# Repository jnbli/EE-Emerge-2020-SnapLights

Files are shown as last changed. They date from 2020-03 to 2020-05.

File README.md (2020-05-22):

# SnapLights

Snaplights is project that uses face recognition and clap detection to play the game of tic-tac-toe. It is a two-player game. In this project, 9 [Adafruit Neopixel LEDs](https://www.adafruit.com/product/1487) are arranged in 3-by-3 patterns in a wooden frame with a camera and a microphone attached to the frame. The [Open MV H7](https://openmv.io/products/openmv-cam-h7) camera is used for the face recognition, [KY-037 Microphone sensor](http://sensorkit.en.joy-it.net/index.php?title=KY-037_Microphone_sensor_module_(high_sensitivity)) for the clap detection, and the neopixels to display the output. Players choose their spot with their face and double clap to confirm. The first to claim three spots in a row wins!

# Getting Started

The early idea was to have a finger snap turn on a set of lights, by Jonathan. In discussions, Aldric convinced the team to pivot the project to be an interactive game. 

# How does Snaplights work? 
The control system of Snaplights, the MSP430G2553 is programmed using the Texas Instruments Code Composer. The code creats a UART connection between the camera and the microntroller. It also process the signal received from the microphone. The OpenMV H7 camera is programmed using OpenMV IDE, the code splits the camera lens screen into 3x3 matrices coordinates. If the face is detected in any of the sections, the corresponding neopixel will turn on to be X for the first player and at the same time if the microphone senses a clap then the displayed X will be locked in the neopixel. If a clap is not sensed then as the person moves their face onto a different section, the corresponding neopixel will turn on, turning off the previous neopixel. After locking the first input, the next player will start playing with O and follow the same process as X. 

# Assembly
This is the general assembly of the mechanical components of our project. It consists of a wooden frame, another foamboard frame to be placed within the larger frame, nine 3D printed grid assemblies to dissipate light to a greater area, and nine neopixels. 
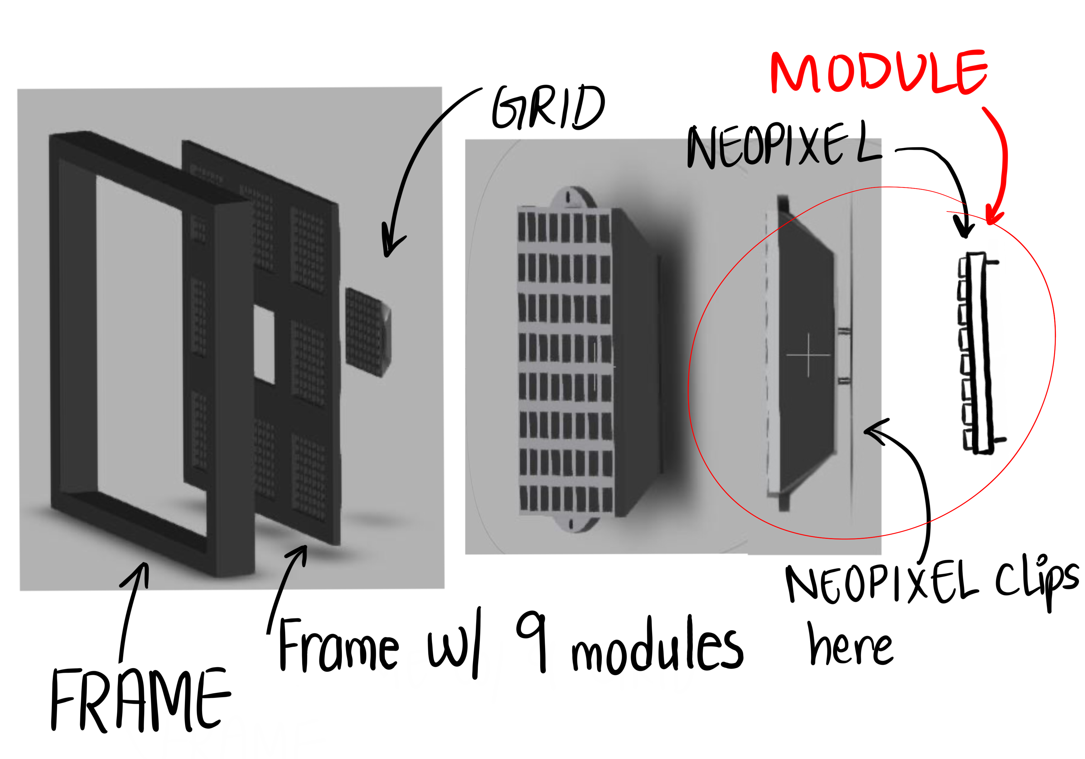
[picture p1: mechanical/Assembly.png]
Assembly


# Wiring Diagram
This is the wiring configuration of Snaplights. The diagram presents how the wires connects all the part together. DaisyChain is the type of wiring scheme used for the neopixels. 
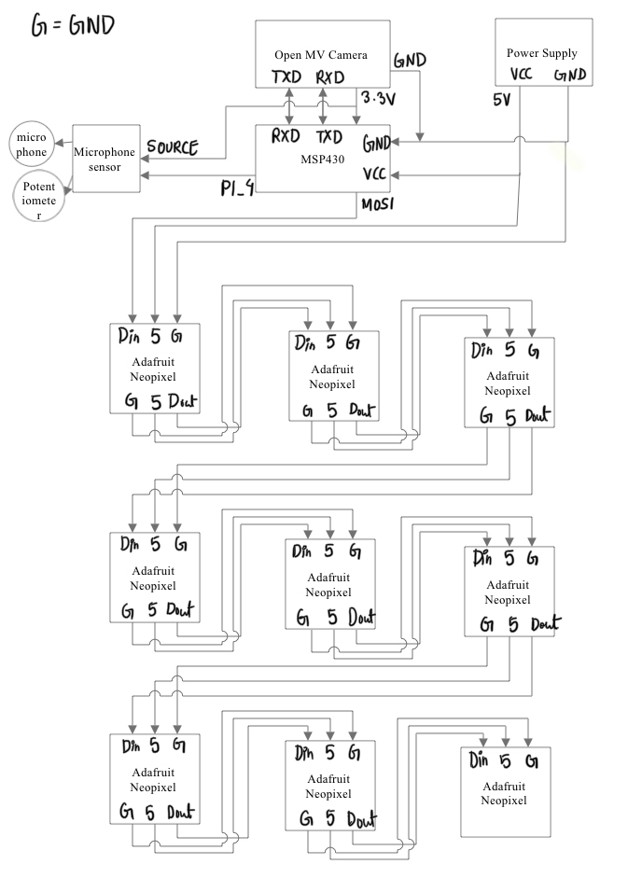
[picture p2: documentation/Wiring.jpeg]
Wiring Diagram


# Project Team

* **[Anshu Paudyal](https://github.com/anshupaudyal)** - *Contributed on 3D modeling, hardware, and software for Snaplights*
* **[Aldric Sangalang](https://github.com/AldricSangalang)** - *Hardware Lead*
* **[Jonathan Li](https://github.com/jnbli)** - *Software Lead*
* **[Sean Alling](https://github.com/SeanAlling)** - *Teaching Assistant*
* **Andre Knoesen** - *EE-Emerge Professor*

**[Back to top](#table-of-contents)**

# Acknowledgments
Thank you to Justin Wong and Raunaq Chopra for helping in the Fall and to Aakansha Bhatt for helping in Winter. A big thank you to TA Sean Alling, who guided us and helped us with important aspects of the project. And a big thank you to Professor Knoesen for the help and guidance.

Also we would like to thank Texas Instruments for sponsoring us and UC Davis for providing us the facility to build our project.

**[Back to top](#table-of-contents)**

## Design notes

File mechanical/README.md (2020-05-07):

# Assembly

This is the general assembly of the mechanical components of our project. It consists of a wooden frame, another foamboard frame to be placed within the larger frame, nine 3D printed grid assemblies to dissipate light to a greater area, and nine neopixels. 

Assembly

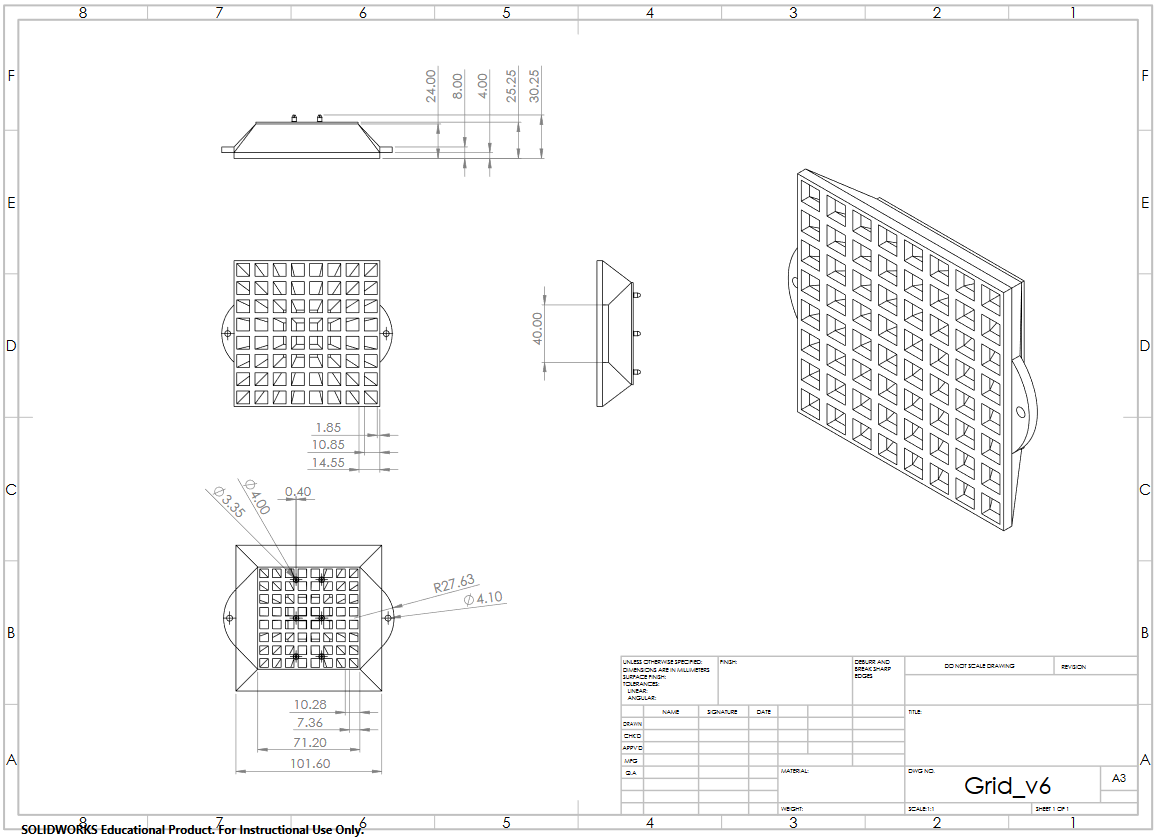
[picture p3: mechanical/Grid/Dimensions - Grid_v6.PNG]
Grid Dimensions


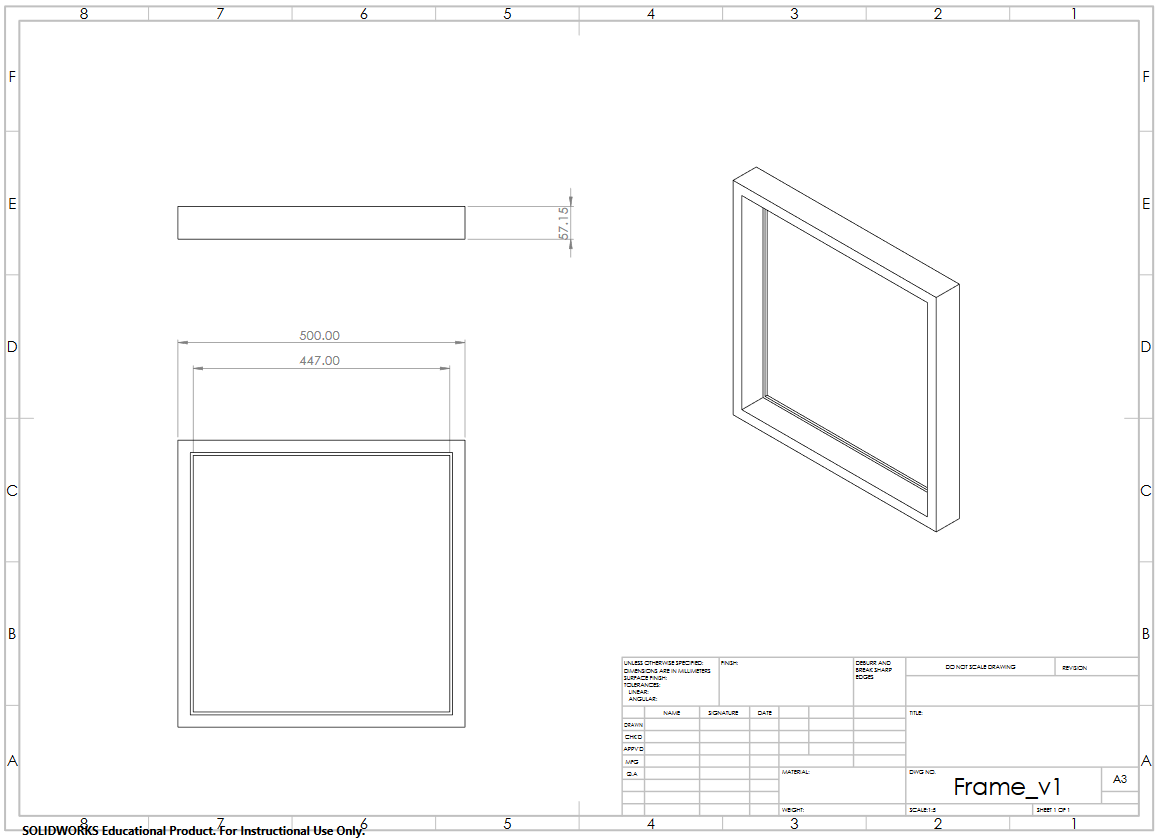
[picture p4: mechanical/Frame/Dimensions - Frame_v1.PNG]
Frame Dimensions


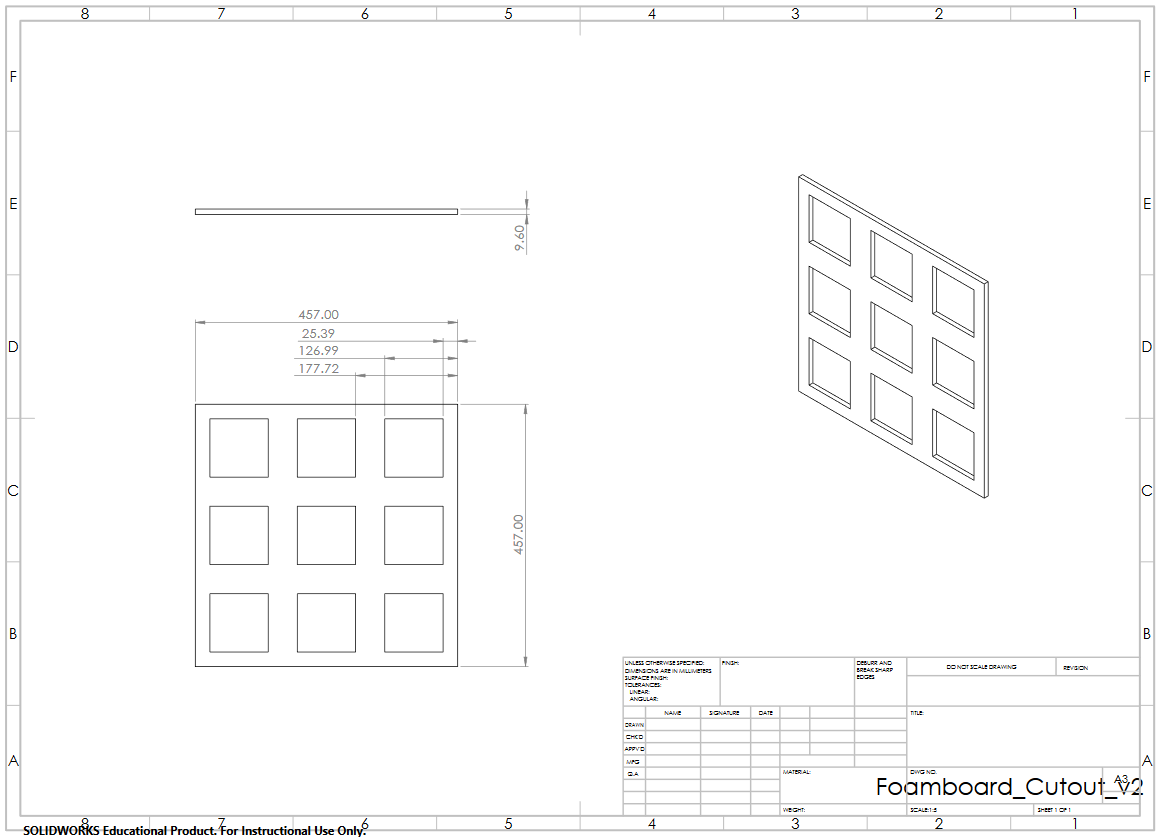
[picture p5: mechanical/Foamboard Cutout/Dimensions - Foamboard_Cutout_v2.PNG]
Foamboard Dimensions


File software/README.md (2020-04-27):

# Software
Our project involves a board and two sensors, which are a camera and microphone.

# Board
The Texas Instruments MSP430 microcontroller is the brains. It processes the data coming from the two sensors (camera, microphone) and controls LEDs grid display. The code is in Energia, which is essentially C++. 

# Camera
The OpenMV Camera detects in its field of view which of the nine quadrants a face is in. Then, through UART, it and sends the information to the board. The board then knows which of the nine Neopixel LEDs to light up. The Camera is coded in Python.

# Microphone
The KY-037 digital microphone amplifies sound using an op-amp and converts it to a digital signal, which it then sends over one pin to the board. Because a double clap is distinct, the board can tell when a user confirms his spot on the 3x3 Neopixel Grid. To use the microphone, the board only needs to include a sound pin.

# LEDs
Adafruit Neopixels are the LED of choice as they can display X and O in many colors. To interface with the Neopixels, the board needs to import the Adafruit Neopixel libraries.

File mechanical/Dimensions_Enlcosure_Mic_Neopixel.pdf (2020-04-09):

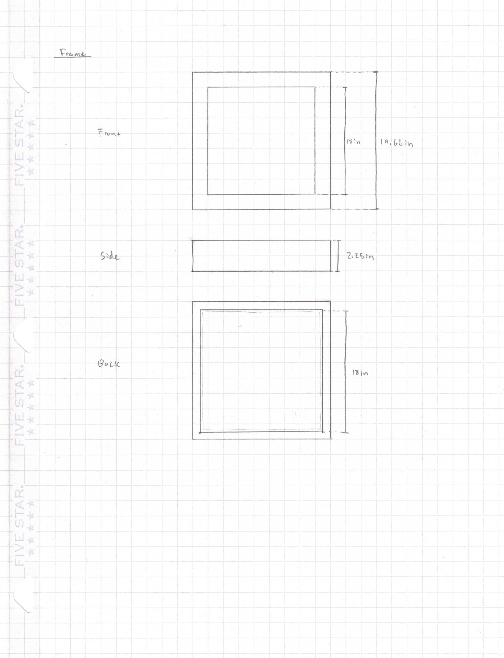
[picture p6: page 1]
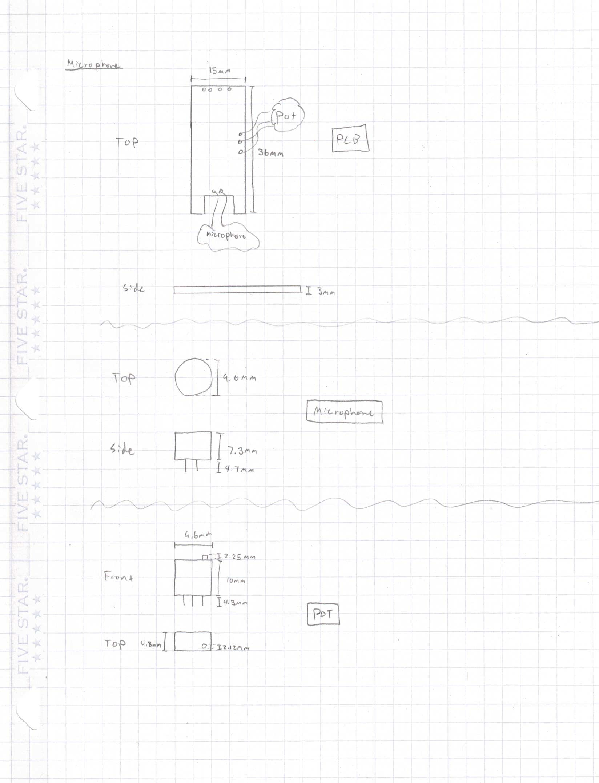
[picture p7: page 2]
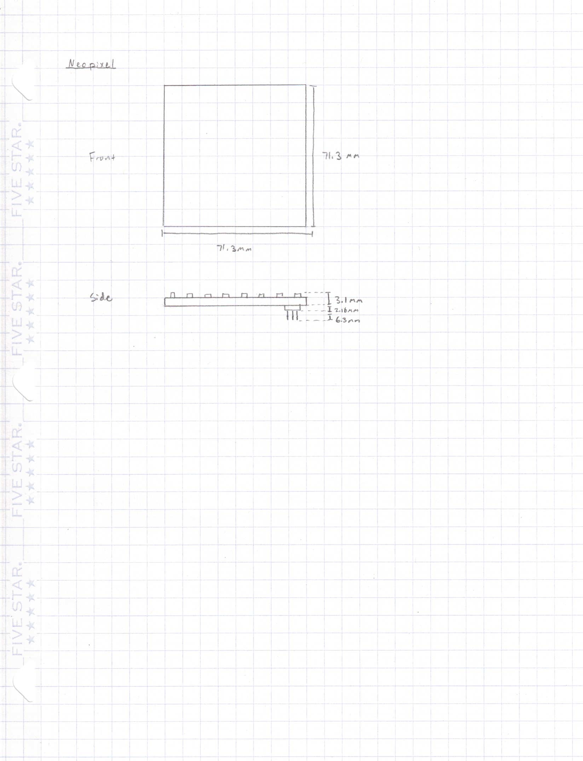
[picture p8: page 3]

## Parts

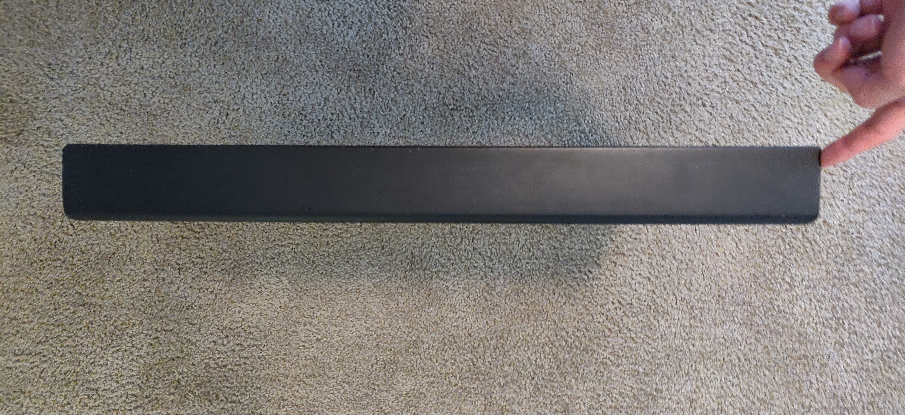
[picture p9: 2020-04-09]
documentation/Enclosure & Parts Reference Pictures/Frame/Side.jpg

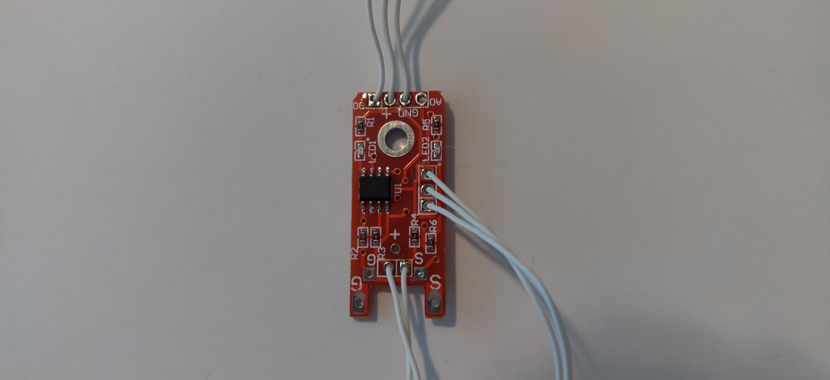
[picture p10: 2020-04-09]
documentation/Enclosure & Parts Reference Pictures/Microphone/PCB_Top.jpg

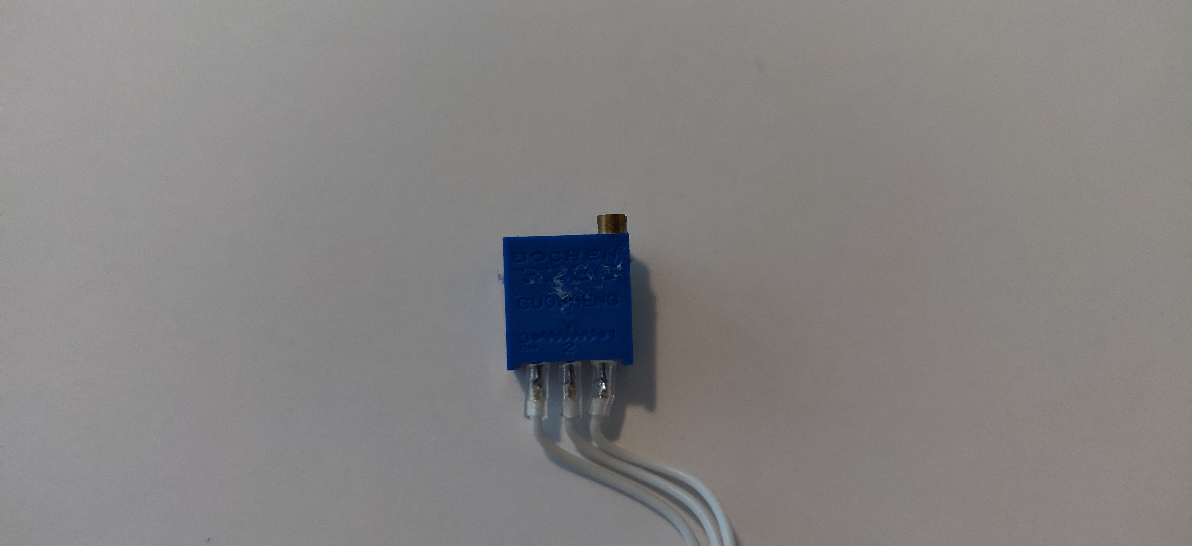
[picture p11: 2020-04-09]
documentation/Enclosure & Parts Reference Pictures/Microphone/Pot_Side.jpg

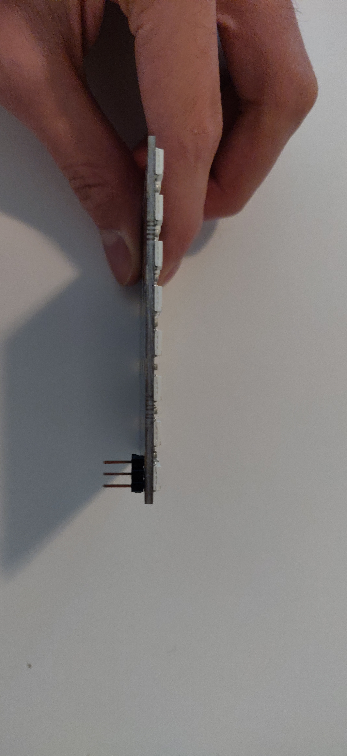
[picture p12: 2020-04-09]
documentation/Enclosure & Parts Reference Pictures/Neopixel/Side.jpg

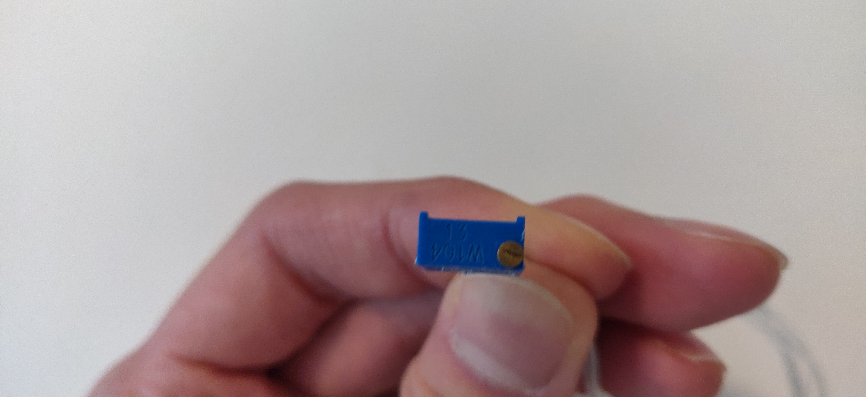
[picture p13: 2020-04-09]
documentation/Enclosure & Parts Reference Pictures/Microphone/Pot_Top.jpg

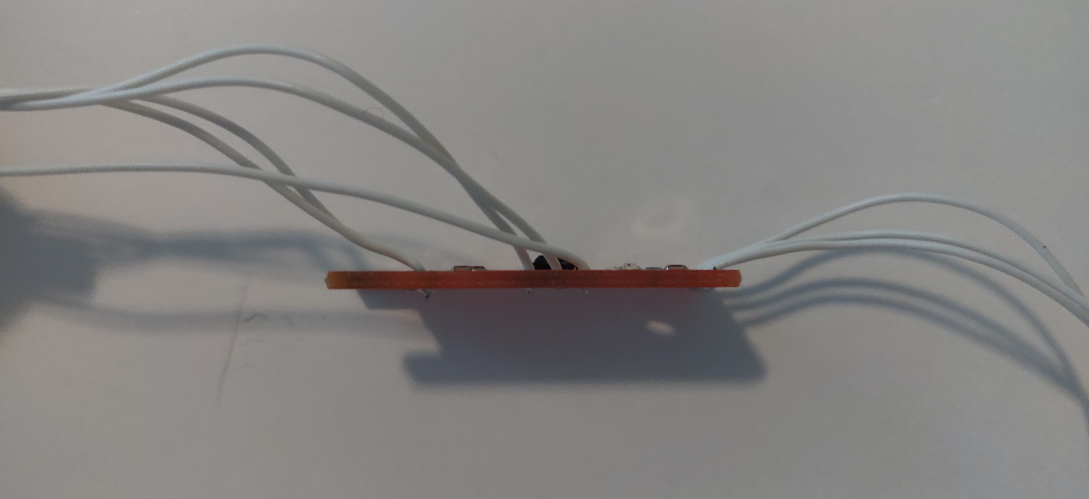
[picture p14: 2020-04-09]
documentation/Enclosure & Parts Reference Pictures/Microphone/PCB_Side.jpg

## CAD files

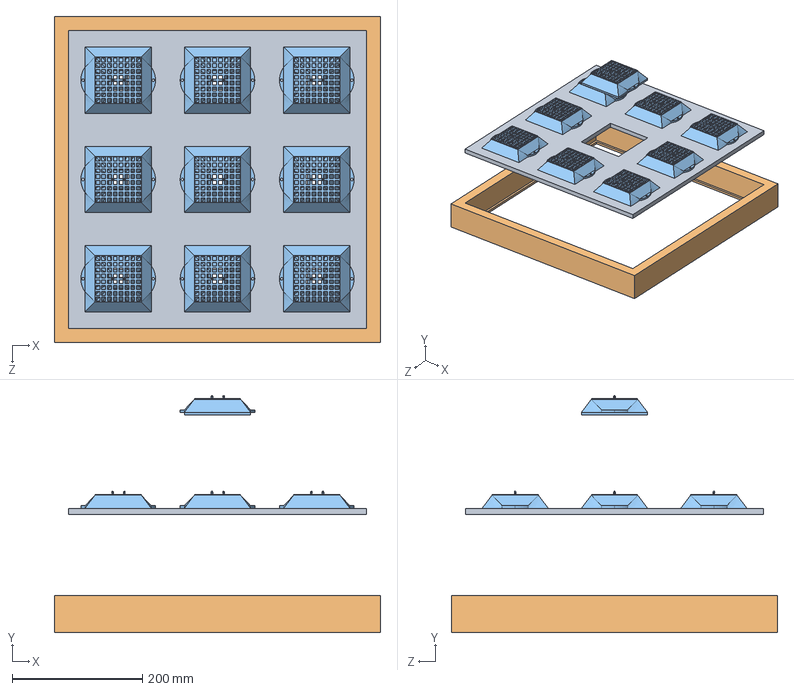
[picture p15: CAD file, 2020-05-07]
mechanical/Assembly/Assembly_Frame&Modules_v2.STEP
500.0 x 364.2 x 500.0 mm
Foamboard_Cutout_v2
Frame_v1
Grid_v5 x 9

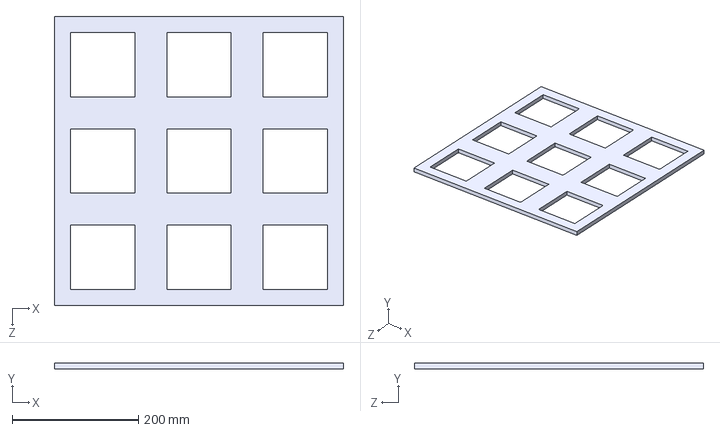
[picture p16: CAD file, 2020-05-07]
mechanical/Foamboard Cutout/Foamboard_Cutout_v2.STEP
457.0 x 9.60 x 457.0 mm

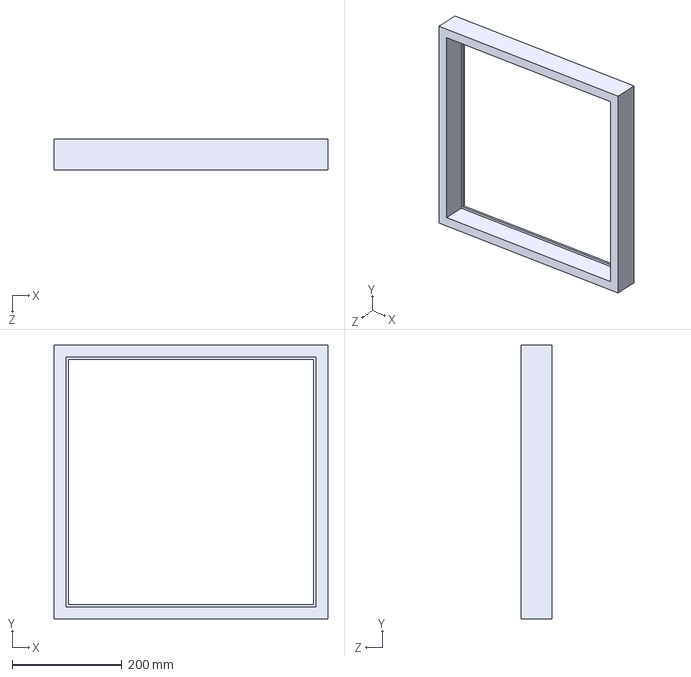
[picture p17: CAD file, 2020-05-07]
mechanical/Frame/Frame_v1.STEP
500.0 x 500.0 x 57.1 mm

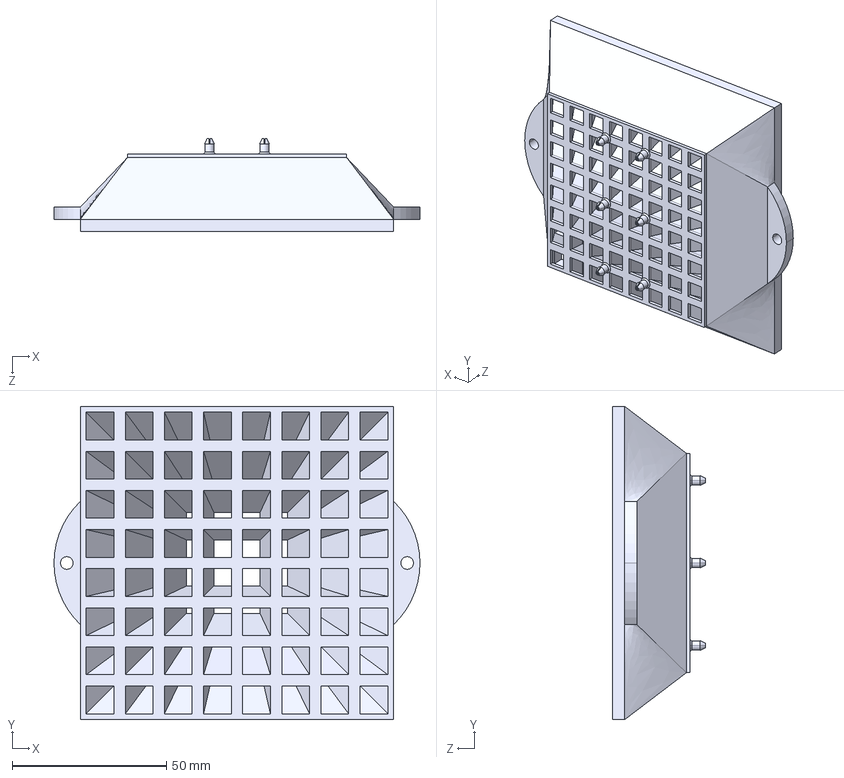
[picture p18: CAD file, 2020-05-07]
mechanical/Grid/Grid_v6.STEP
118.7 x 101.6 x 30.3 mm

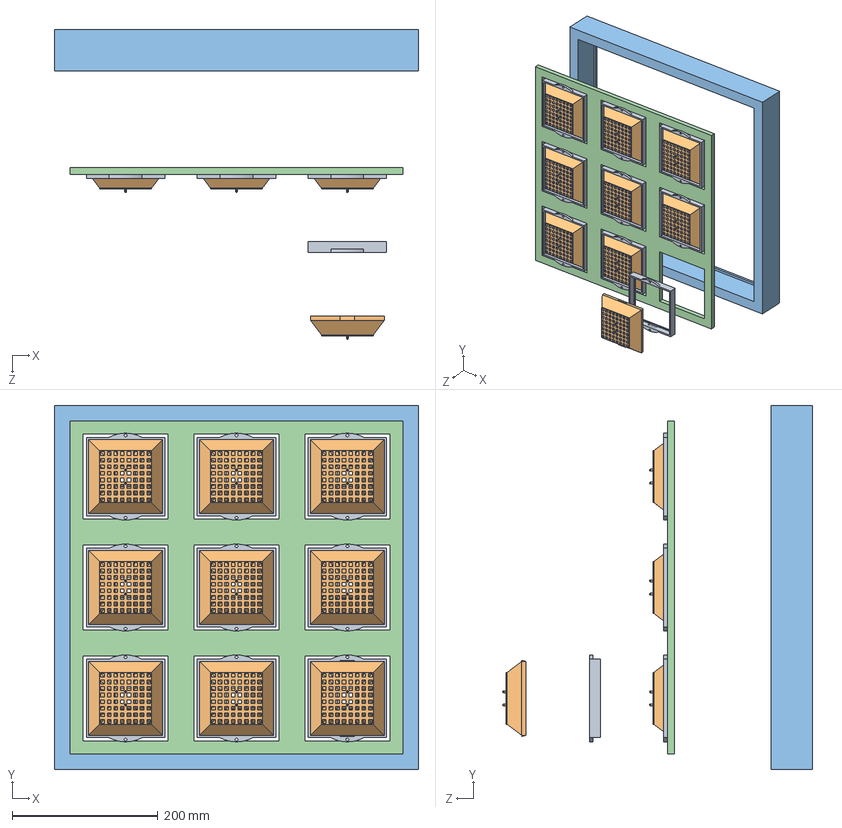
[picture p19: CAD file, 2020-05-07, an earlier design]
mechanical/Assembly/Assembly_Frame&Modules_v1.STEP
500.0 x 500.0 x 425.5 mm
Casing_v1 x 9
Grid_v3 x 9
Frame_v1
Foamboard_Cutout_v1

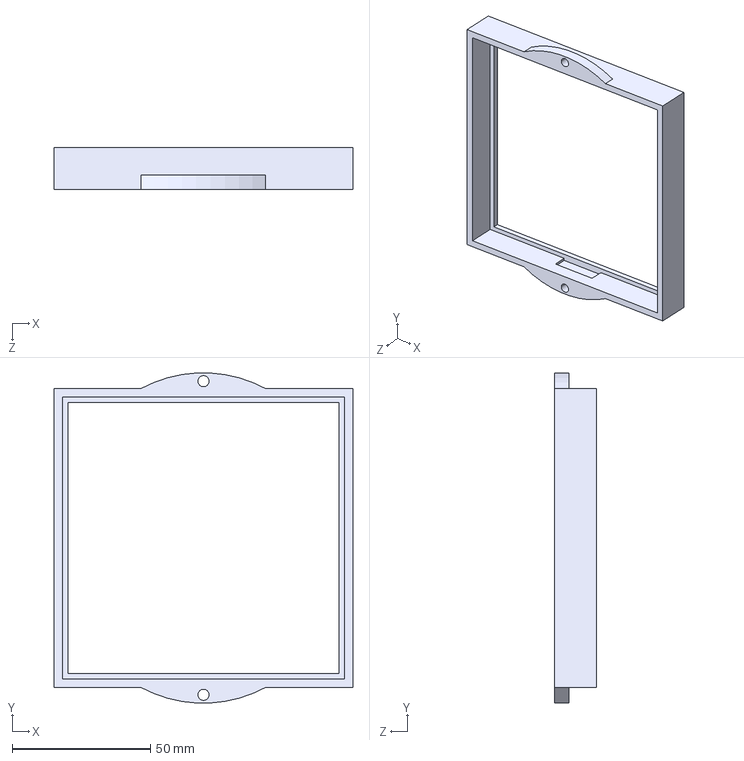
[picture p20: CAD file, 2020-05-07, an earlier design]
mechanical/Casing (Unused)/Casing_v1.STEP
108.0 x 119.2 x 15.0 mm

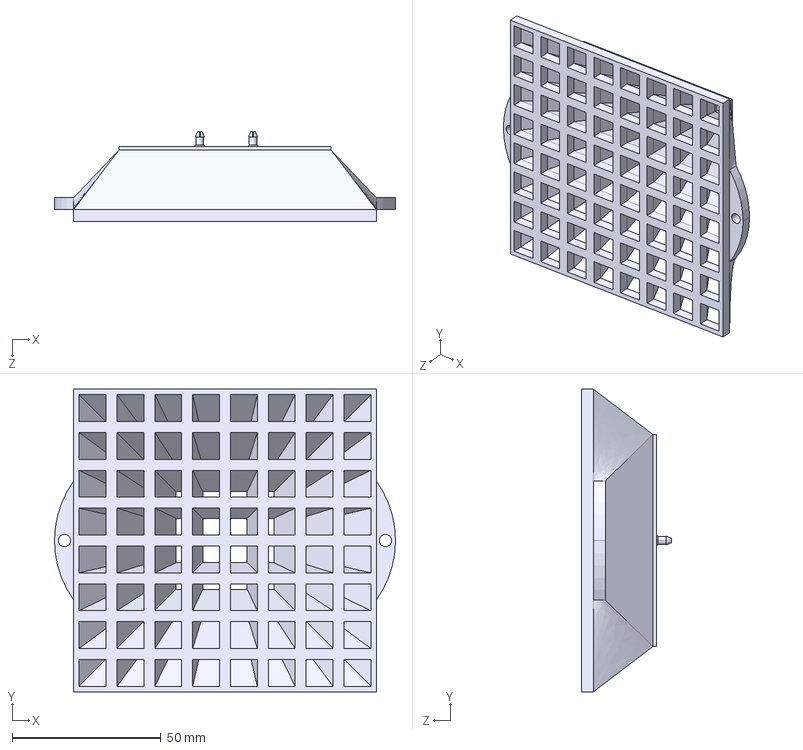
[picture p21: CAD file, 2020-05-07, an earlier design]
mechanical/Grid/Grid_v5.STEP
114.5 x 101.6 x 30.3 mm

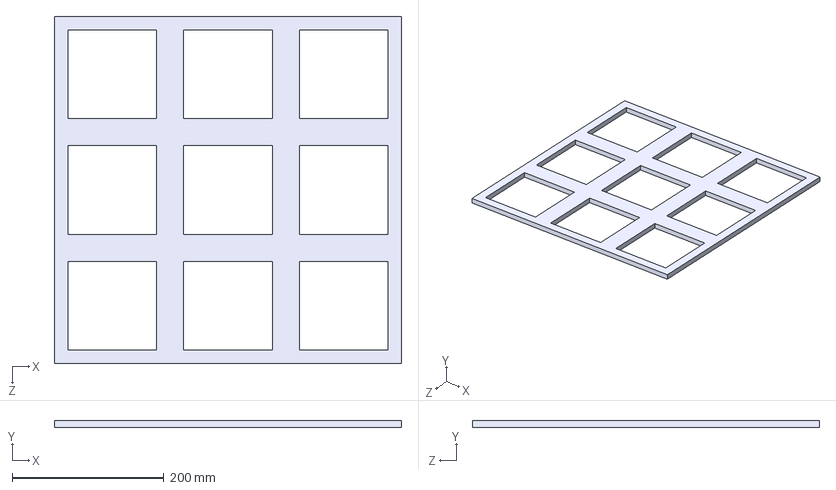
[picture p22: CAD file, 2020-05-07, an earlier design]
mechanical/Foamboard Cutout/Foamboard_Cutout_v1.STEP
457.0 x 9.60 x 457.0 mm

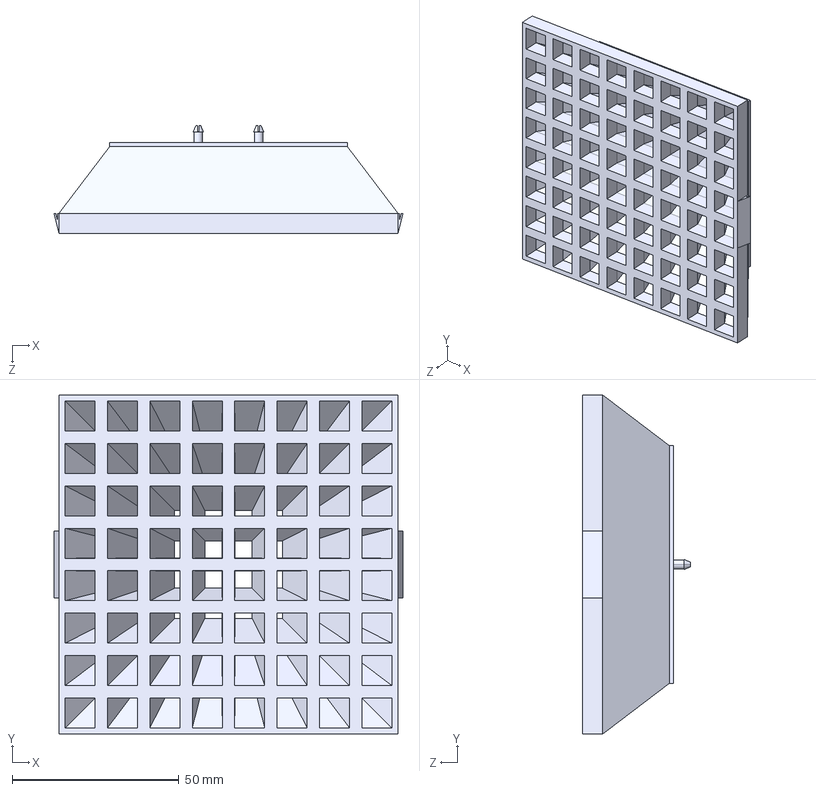
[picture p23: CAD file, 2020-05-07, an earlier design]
mechanical/Grid/Grid_v3.STEP
104.6 x 101.6 x 32.3 mm

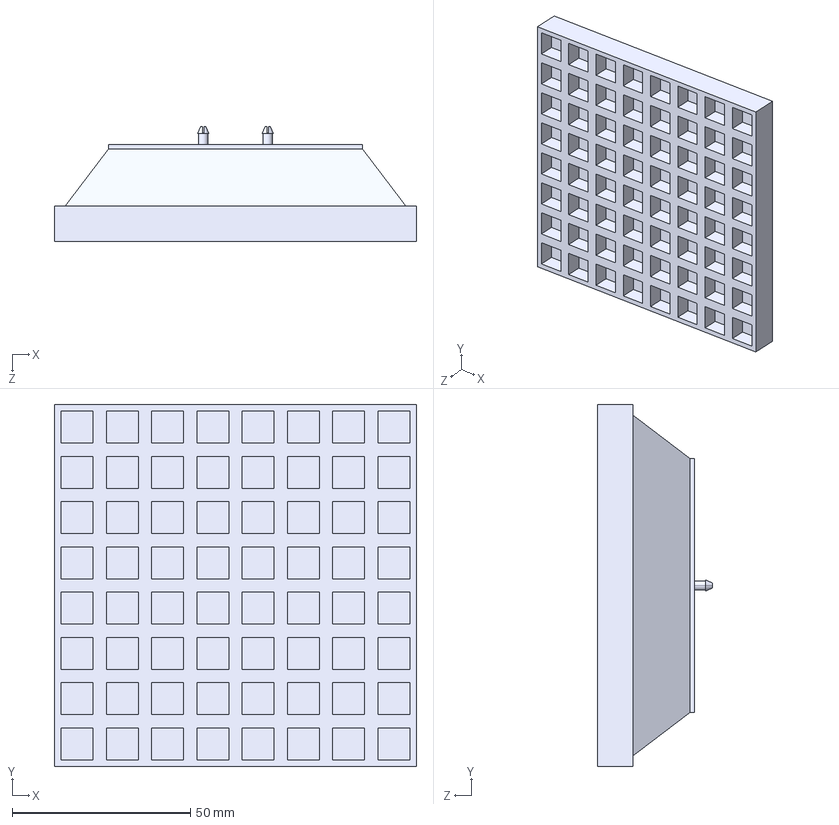
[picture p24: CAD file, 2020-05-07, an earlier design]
mechanical/Grid/Grid_v4.STEP
101.6 x 101.6 x 32.3 mm

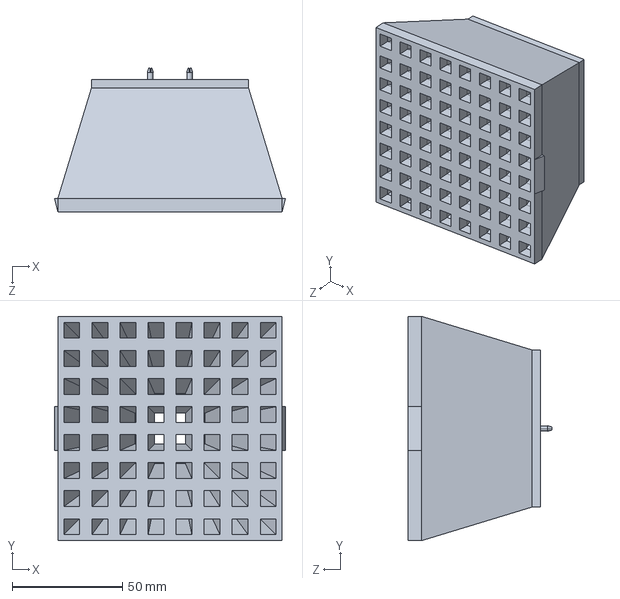
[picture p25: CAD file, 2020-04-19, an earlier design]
mechanical/Grid/Grid_v2.STEP
104.6 x 101.6 x 65.0 mm

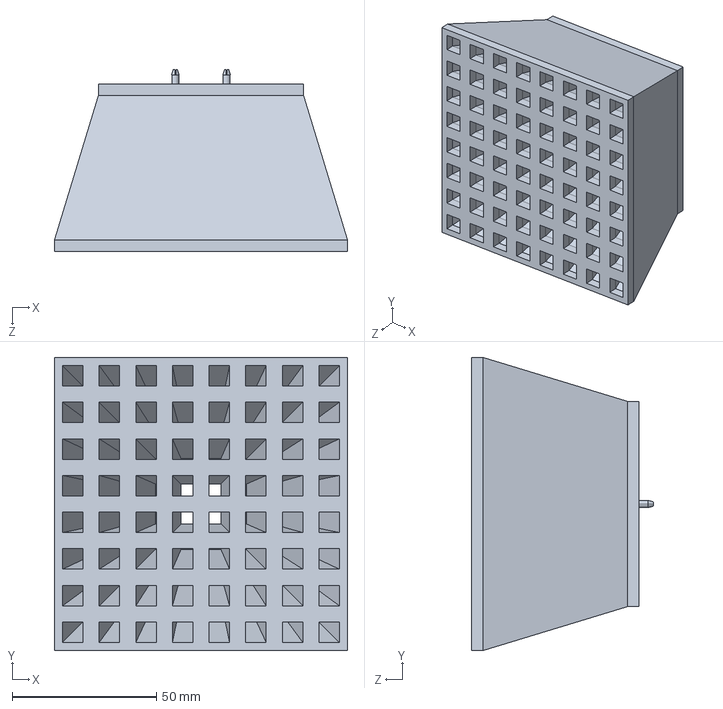
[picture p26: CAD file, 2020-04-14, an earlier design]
mechanical/Grid/Grid_v1.STEP
101.6 x 101.6 x 63.0 mm

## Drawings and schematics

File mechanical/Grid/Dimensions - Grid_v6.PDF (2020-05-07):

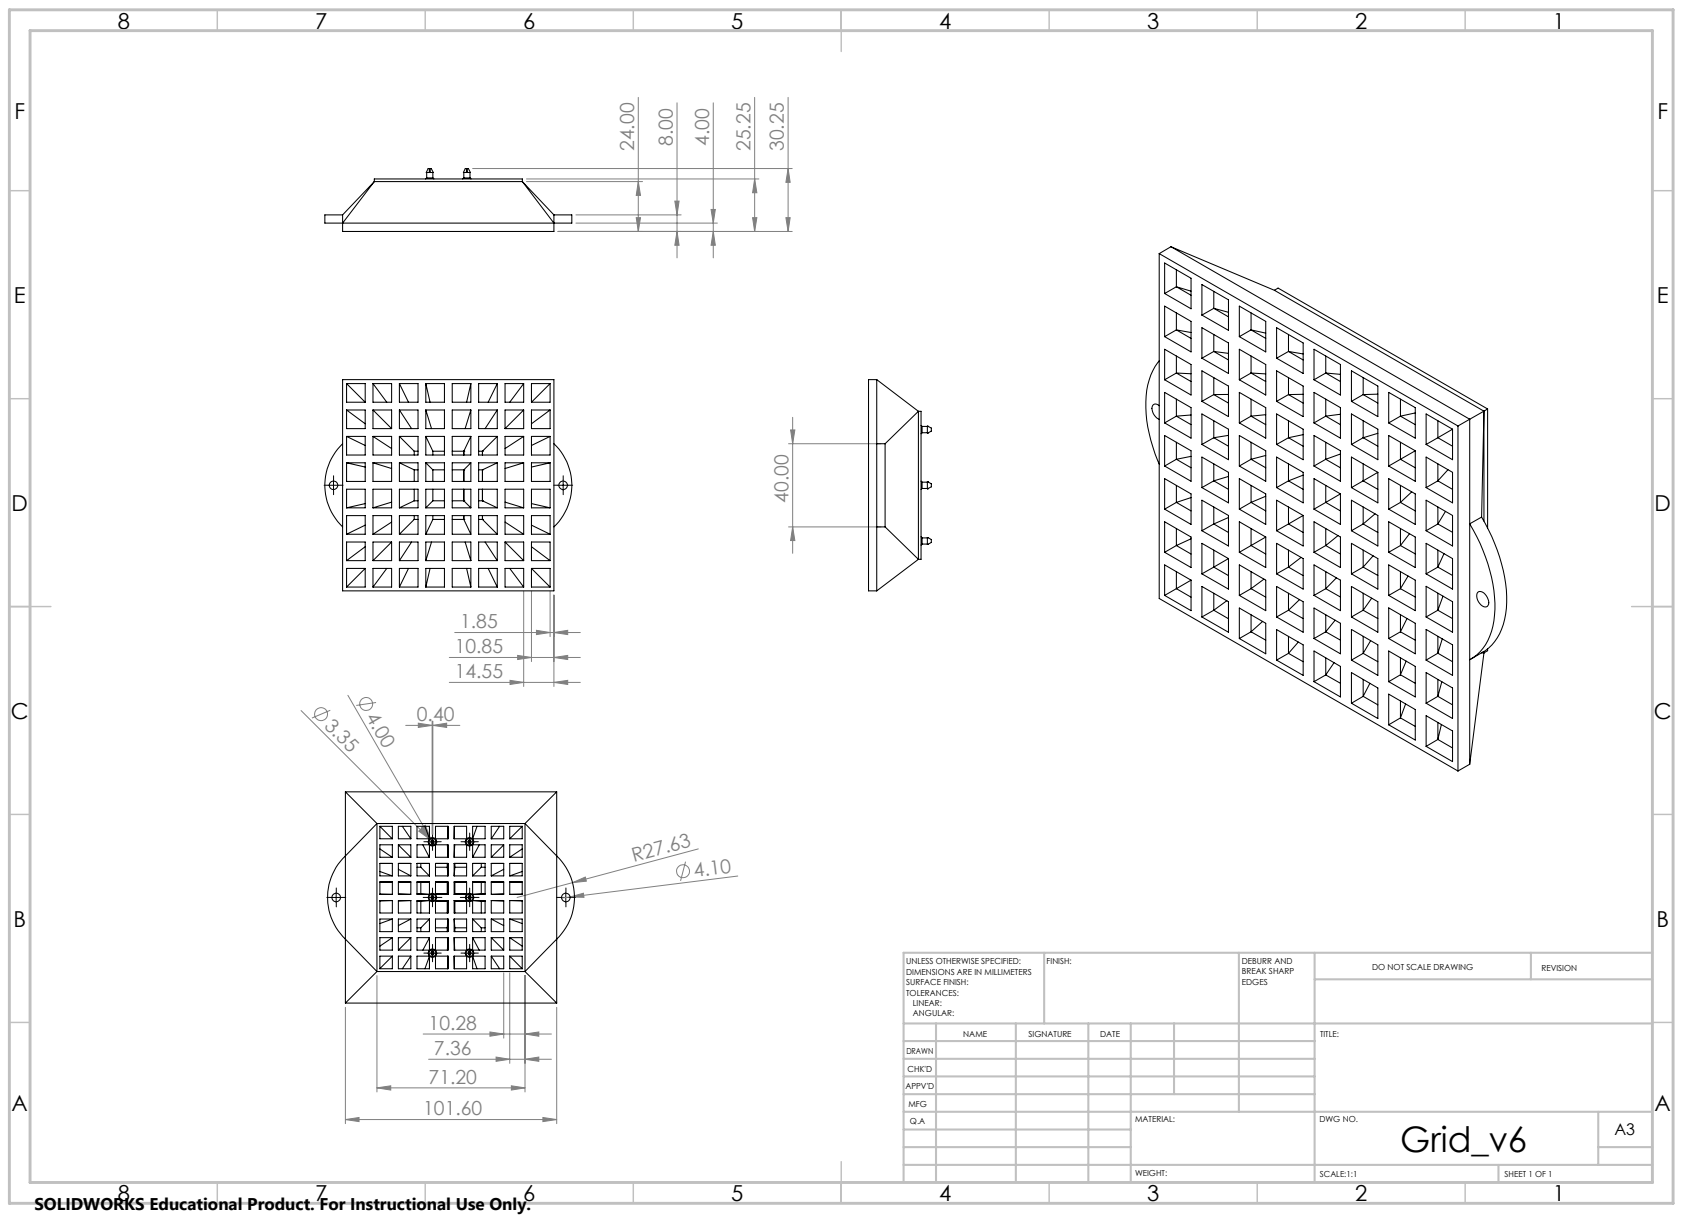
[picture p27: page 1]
FINISH:; DEBURR AND; BREAK SHARP; DO NOT SCALE DRAWING; REVISION; SCALE:1:1; SHEET 1 OF 1

UNLESS OTHERWISE SPECIFIED:
DIMENSIONS ARE IN MILLIMETERS
SURFACE FINISH:
TOLERANCES:
LINEAR:
ANGULAR:

NAME | SIGNATURE | DATE | TITLE:

DRAWN

APPV'D
MFG
Q.A | MATERIAL: | DWG NO. Grid_v6 | A3

SOLIDWORKS Educational Product. For Instructional Use Only.

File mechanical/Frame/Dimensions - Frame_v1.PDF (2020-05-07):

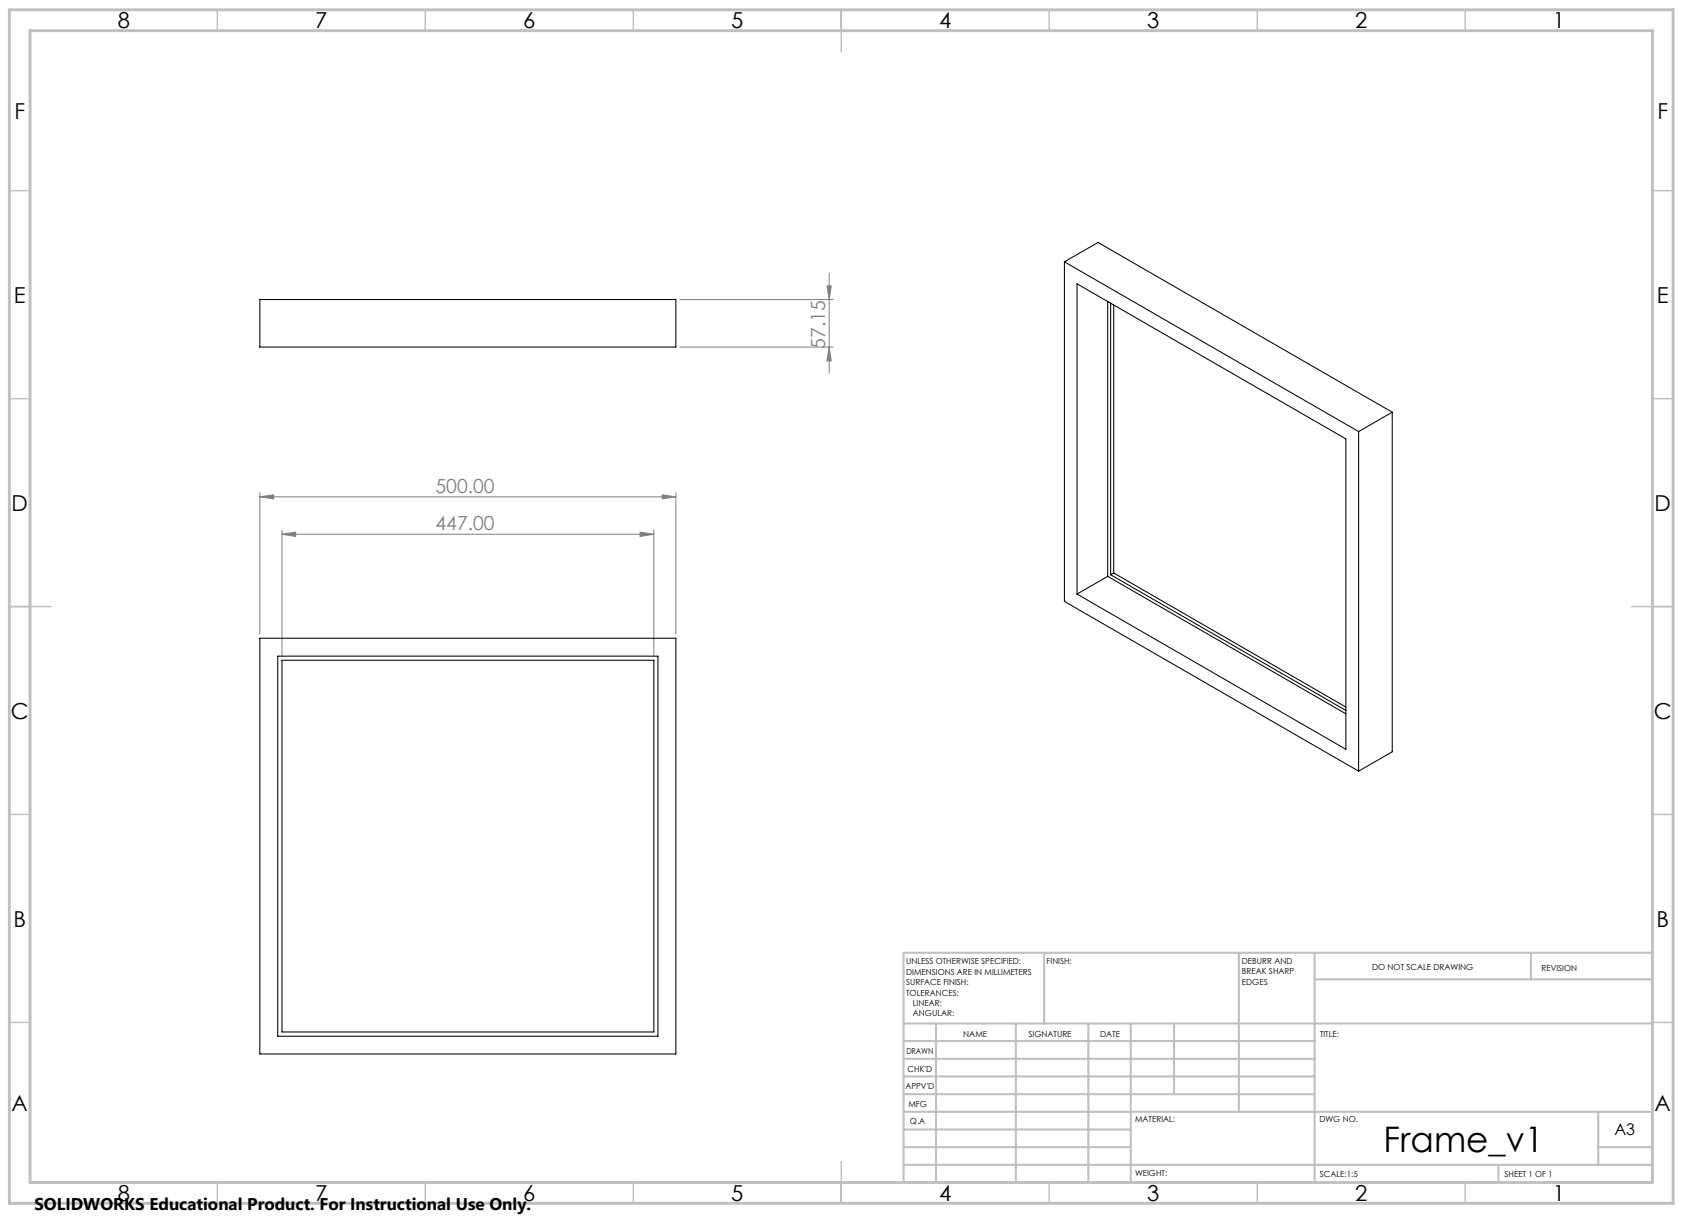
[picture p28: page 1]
FINISH:; DEBURR AND; BREAK SHARP; DO NOT SCALE DRAWING; REVISION; SCALE:1:5; SHEET 1 OF 1

UNLESS OTHERWISE SPECIFIED:
DIMENSIONS ARE IN MILLIMETERS
SURFACE FINISH:
TOLERANCES:
LINEAR:
ANGULAR:

NAME | SIGNATURE | DATE | | | | TITLE:

DRAWN
CHK'D
APPV'D
MFG
Q.A | | | | MATERIAL: | DWG NO. Frame_v1 | A3

SOLIDWORKS Educational Product. For Instructional Use Only.

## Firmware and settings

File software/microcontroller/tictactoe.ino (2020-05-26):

#include <msp430.h>
#include "ws2812.h"

#include <stdint.h>

#define soundPin P1_4

int sensorValue = 0;
int eventstatus = 0;

int grid[9] = {2, 2, 2, 
               2, 2, 2, 
               2, 2, 2}; // 0 means O, 1 means X, 2 means nothing

void toggleLED()
{
    static     uint8_t state = 0;
    if(state==0)
    {
        state = 0;
        P1OUT &= ~BIT0;   
    }
    else
    {
        state = 0;
        P1OUT |= BIT0;      // else LED ON
    }
}

void setup(void) 
{
    Serial.begin(9600);
    initStrip();  
    pinMode(soundPin, INPUT);
}
  
void loop () 
{
    bool exitClap = 0;
    int current = 9;
    int player = 0; // 0 means O, 1 means X
    int tieCounter = 0;
    for(int i = 0; i < 9; i++){
        grid[i] = 2;
    }
    
    
    do {
        if (Serial.available() > 0) {
            // Read the most recent byte
            int intRead = Serial.read() - 48;
            
            // swap edges due to its wiring
            if (intRead == 0) 
              intRead = 2;
            else if (intRead == 2) 
              intRead = 0;
            else if (intRead == 3)
                intRead = 5;
            else if (intRead == 5)
                intRead = 3;
            else if (intRead == 6)
                intRead = 8;
            else if (intRead == 8)
                intRead = 6;
    
            // limit intRead < 9 because we have 9 LEDs
            if (current != intRead && intRead < 9) {
    
                current = intRead;
                clearStrip();
    
                draw(player, intRead, COLOR_RED);
                drawGrid(COLOR_BLUE); //Draws whatever is in grid 
                showStrip();
            }
        }
    
        if (current != 9 && doubleClap() && grid[current] == 2) { //returns 1 or 0
        	grid[current] = player; //saves player choice in grid array
        	clearStrip();
        	drawGrid(COLOR_BLUE);
        	showStrip();
                
            player = 1 - player;
            tieCounter = tieCounter + 1;
        }
        
        if(isWinner()) {
            delay(2000);
            clearStrip();
            fillStrip(COLOR_OFF);
    
            int winner = 1-player;
            
            draw(winner, 0, COLOR_GREEN);
            draw(winner, 1, COLOR_GREEN);
            draw(winner, 2, COLOR_GREEN);
            drawW(64*3, COLOR_GREEN);
            drawO(64*4, COLOR_GREEN);
            drawN(64*5, COLOR_GREEN);
            draw(winner, 6, COLOR_GREEN);
            draw(winner, 7, COLOR_GREEN);
            draw(winner, 8, COLOR_GREEN);
          
            showStrip();
            while(exitClap == 0) {
                exitClap = doubleClap();
            }
        }
        
        if(tieCounter == 9 && isWinner() == false){
            delay(2000);
            clearStrip;
            fillStrip(COLOR_OFF);
            
            drawT(64*3, COLOR_GREEN);
            drawI(64*4, COLOR_GREEN);
            drawE(64*5, COLOR_GREEN);
            
            showStrip();
            while(exitClap == 0) {
                exitClap = doubleClap();
            }
        }
    } while(exitClap == 0);
}

bool isWinner() {

    if (grid[0] != 2 && grid[0] == grid[1] && grid[0] == grid[2] && grid [1] == grid[2]) { // horizontals
      return true;
    }
    else if (grid[3] != 2 && grid[3] == grid[4] && grid[3] == grid[5] && grid[4] == grid[5]) {
      return true;
    }
    else if (grid[6] != 2 && grid[6] == grid[7] && grid[6] == grid[8] && grid[7] == grid[8]) {
      return true;
    }
    else if (grid[2] != 2 && grid[2] == grid[5] && grid[2] == grid[8] && grid[5] == grid[8]) { // verticals
      return true;
    }
    else if (grid[1] != 2 && grid[1] == grid[4] && grid[1] == grid[7] && grid[4] == grid[7]) {
      return true;
    }
    else if (grid[0] != 2 && grid[0] == grid[3] && grid[0] == grid[6] && grid[3] == grid[6]) {
      return true;
    }
    else if (grid[2] != 2 && grid[2] == grid[4] && grid[2] == grid[6] && grid[4] == grid[6]) { // diagonals
      return true;
    }
    else if (grid[0] != 2 && grid[0] == grid[4] && grid[0] == grid[8] && grid[4] == grid[8]) {
      return true;
    }
    return false;
}

void drawGrid(ColorMap color) {
    for (int i=0; i<9; i++) {
        if (grid[i] != 2) {
            draw(grid[i], i, color);
        }
    }

}


void draw(int player, int position, ColorMap color) {
    if (player == 0) {
        drawCircle(position*64, color);
    }
    else if (player == 1) {
        drawCross(position*64, color);
    }
}


void drawCross(int k, ColorMap color) {
  for(int i=0; i<8; i++) {
    for(int j=0; j<8; j++) {
      if (i == j || 7-j == i) {
        // a little different
        setLEDColor(i*8+j+k, color);
      }
    }
  }
}


void drawCircle(int k, ColorMap color) {
  for(int i=0; i<8; i++) {
    for(int j=0; j<8; j++) {
      if ((i == 0 && j >=2 && j <= 5) ||
          (i == 1 && j == 1) || 
          (i == 6 && j == 1) ||
          (i == 1 && j == 6) ||
          (i == 6  && j == 6) || 
          (j == 0 && i >= 2 && i <= 5) || 
          (j == 7 && i >= 2 && i <= 5) || 
          (i == 7 && j >=2 && j <= 5)) {
            setLEDColor(i*8+j+k, color);
      } 
    }
  }
}


void drawW(int k, ColorMap color) {
  for(int i=0; i<8; i++) {
    for(int j=0; j<8; j++) {
      if ((i == 0 || i == 7) || 
         (i == j && i < 4) || 
         (i == 4 && j == 3) ||
         (i == 5 && j == 2) ||
         (i == 6 && j == 1)){
        setLEDColor(i*8+j+k, color);
      }
    }
  }
}


void drawO(int k, ColorMap color) {
  drawCircle(k, color);
}


void drawN(int k, ColorMap color) {
  for(int i=0; i<8; i++) {
    for(int j=0; j<8; j++) {
      if (i == 0 || i == 7 || (i == 7-j)){
        setLEDColor(i*8+j+k, color);
      }
    }
  }
}

void drawT(int k, ColorMap color) {
  for(int i=0; i<8; i++) {
    for(int j=0; j<8; j++) {
      if (i == 3 || i == 4 || j == 7 || j == 6){
        setLEDColor(i*8+j+k, color);
      }
    }
  }
}

void drawI(int k, ColorMap color) {
  for(int i=0; i<8; i++) {
    for(int j=0; j<8; j++) {
      if (i == 6 || i == 7 || j == 4 || j == 3 || i == 1 || i == 0){
        setLEDColor(i*8+j+k, color);
      }
    }
  }
}

void drawE(int k, ColorMap color) {
  for(int i=0; i<8; i++) {
    for(int j=0; j<8; j++) {
      if (i == 0 || i == 1 || (j != 5 && j != 2)){
        setLEDColor(i*8+j+k, color);
      }
    }
  }
}


bool doubleClap() {
  eventstatus = 0;  
  sensorValue = digitalRead(soundPin);  
  delay(1);
  
  if(eventstatus == 0){
    if(sensorValue == 1){
      eventstatus = 1;      
    }
  }
  
    if(eventstatus == 1){  
    for(int k = 10; k > 0; k--){
      delay(10);
      sensorValue = digitalRead(soundPin);
      if(sensorValue == 0){
        eventstatus = 2;
        break;
      }      
    }
  }
  
  if(eventstatus == 2){
    for(int n=500; n>0; n--){
      delay(1);
      sensorValue = digitalRead(soundPin);
      if(sensorValue == 1){
        eventstatus = 3;
      break;
      }
    }
  }
  
  if(eventstatus == 3){
    return true;
  }
  
  return false;
}

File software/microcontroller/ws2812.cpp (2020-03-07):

#include "ws2812.h"

#ifndef SIMULATE
#include <msp430.h>
#else
#include<stdio.h>
#endif

/*
    Number of leds corresponds to the amount of leds that should be used. 
    The divide by 8 + 1 makes the system use the least amount of bytes to 
    represent all of the LEDs. 
*/
#define LED_ARRAY_SIZE (NUM_LEDS/4 + 1)


// WS2812 takes GRB format
typedef struct {
   uint8_t green;
   uint8_t red;
   uint8_t blue;
} LED;

 /*
    Each LED can have one of 4 defined colors. Each 8 bits holds 4 leds. This is done to make the 
    ram consumption more efficient. Compared to the naive way of using 3 bytes per led this will use 
    1/4 byte per led, a 12 fold decrease in ram consumption. 
 */
static uint8_t leds[LED_ARRAY_SIZE];

/*
    Defines the color mapping between the 2 bit color and the represented color
    Declared static const so that this is placed in flash and not ram
*/
static const LED ColorMapValues[NUM_COLOR] =
{
    {0x00, 0x00, 0x00}, //COLOR_OFF
    {0x00, 0x0F, 0x00}, //COLOR_GREEN,
    {0x0F, 0x00, 0x00}, //COLOR_RED,
    {0x00, 0x00, 0x0F}  //COLOR_BLUE,
};

/*
    Declared static const so that this is placed in flash and not ram
*/
static const  uint8_t ledBitmasks[NUM_COLOR] =
{
    0x03, // 0b0000_0011 LED 0
    0x0C, // 0b0000_1100 LED 1
    0x30, // 0b0011_0000 LED 2,
    0xC0 // 0b1100_0000 LED 3,
};

// Initializes everything needed to use this library. This clears the strip.
void initStrip() 
{
    #ifndef SIMULATE
    // configure output pin as SPI output
    P1SEL  |= OUTPUT_PIN;    
    P1SEL2 |= OUTPUT_PIN;
    // 3-pin, MSB, 8-bit SPI master
    UCB0CTL0 |= UCCKPH + UCMSB + UCMST + UCSYNC; 
    // SMCLK source (16 MHz)
    UCB0CTL1 |= UCSSEL_2;
    // 16 MHz / 3 = .1875 us per bit
    UCB0BR0 = 3;            
    UCB0BR1 = 0;
    // Initialize USCI state machine
    UCB0CTL1 &= ~UCSWRST;
    #endif   
    // clear the strip
    clearStrip();           
}

// Sets the color of a certain LED (0 indexed)
void setLEDColor(uint32_t ledIndex, ColorMap color) 
{
    uint32_t index = ledIndex/4;
    /*
        4 leds per byte. Get index of the led in the byte
    */
    uint8_t offset = ledIndex%4;

    /*
        And out the 2 bits for the led from the byte

    */
    leds[index] = (leds[index] & ~ledBitmasks[offset]);
    /*
        Or in the color code for the led. Offset is 0->3,
        multiply by 2 to get the correct shift amount.

        color is a value from 0 to 3. 
    */
    leds[index] = (leds[index] | (color<<(2*offset)));
}

// Send colors to the strip and show them. Disables interrupts while processing.
void showStrip() 
{
     #ifndef SIMULATE
    __bic_SR_register(GIE);  // disable interrupts
    #endif
    // send RGB color for every LED
    for (uint32_t i = 0; i < NUM_LEDS; i++) 
    {
        /*
            Create a pointer to the led color codes in memory. 
            take led index number and divide by 8.

            i/4 -> Gives which byte led occupies within leds array.
            i%4 -> Gives index within byte that led occupies.
            (2*(i%4)) -> Shifts the led value to the two LSBs.
            ((leds[i/4]>>(2*(i%4))) returns the color code for the led.
                The color code is in RGB format and will be sent out over the SPI bus to 
                the LEDs.


            This was reworked so that it sends the same 3 tuple out on the spi bus as before 
            but it first extracts the color code value from packed bytes. By doing this there is a
            restriction on the number of colors that can be used by the program but in return the 
            amount of leds that can be addressed stays constant. 


        */

        uint8_t *rgb = (uint8_t *)&ColorMapValues[((leds[i/4]>>(2*(i%4)))&0x03)]; // get GRB color for this LED

        #ifdef SIMULATE
        printf("LED: %d:%d:%d->Raw %02X->Color:\t",i, i/4, i%4,((leds[i/4]>>(2*(i%4)))&0x03));
        #endif
        // send green, then red, then blue
        for (uint32_t j = 0; j < 3; j++) 
        {
           
            #ifndef SIMULATE
            uint8_t mask = 0x80;    // b1000000
            // check each of the 8 bits
            while (mask != 0) 
            {
                while (!(IFG2 & UCB0TXIFG))
                {
                       // wait to transmit
                }
                // most significant bit first
                if (rgb[j] & mask) 
                {        
                    // send 1
                    UCB0TXBUF = HIGH_CODE;  
                } 
                else
                {
                    // send 0
                    UCB0TXBUF = LOW_CODE;   
                }
                mask >>= 1;  // check next bit
            }
            #else
            printf("%02X:",rgb[j]);
            #endif
        }
        #ifdef SIMULATE
        printf("\n");
        #endif
    }

    #ifndef SIMULATE
    // send RES code for at least 50 us (800 cycles at 16 MHz)
    __delay_cycles(800);

    // enable interrupts
    __bis_SR_register(GIE);    
    #else
    printf("\n");
    #endif
}

// Clear the color of all LEDs (make them black/off)
void clearStrip() 
{
    fillStrip(COLOR_OFF);  // black
}

// Fill the strip with a solid color. This will update the strip.
void fillStrip(ColorMap color) 
{
    for (uint32_t i = 0; i < NUM_LEDS; i++) 
    {
        // set all LEDs to specified color
        setLEDColor(i, color);  
    }
}

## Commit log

2020-04-09 Frame, Microphone, and Neopixel Dimensions and Pictures
    [EE-Emerge-2020Project v6.f3d]
2020-04-09 Added wiring diagram
2020-04-13 Create CAD files
2020-04-14 Grid_v1
    Grid to be placed into shell, contains pins to hold neopixels
    [Grid_v1.STEP]
2020-04-19 Extended Front and added Clipping Tabs
    [Grid_v2.STEP]
2020-05-07 Moved to mechanical
    [Grid_v1.STEP]
2020-05-07 3D Models Moved to Mechanical
    [Assembly_Frame&Modules_v1.STEP, Assembly_Frame&Modules_v2.STEP, Casing_v1.STEP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]
2020-05-07 Uploaded Image of Assembly
2020-05-07 Updated image and documentation for mechanical assembly
2020-05-07 Deleted uncropped assembly image
2020-05-07 Added cropped assembly image
2020-05-07 Added assembly image to front page readme
2020-05-26 Fixed "win" added "tie", added reset, cleaned up
    [tictactoe.ino]
